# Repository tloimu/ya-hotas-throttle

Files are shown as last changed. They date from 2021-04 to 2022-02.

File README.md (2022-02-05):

# Yet-Another HOTAS Throttle (YA-HOTAS-THROTTLE)

This 3D printable HOTAS throttle game controller. It connects as a standard USB joystick to Windows without needing to install any software.

It has:

 - 3 axis (throttle, vertical, horizontal) with center detents an all
 - 7 buttons
 - hat switch with 8 directions and press button
 - lock/program button
 - RGB LED indicating state: throttle center (green), locked (red), program (blue)
 - high quality mechanical and electro-mechanical components
 - very smooth and easy throttle action with no stiction
 - adjustable throttle handle angle (twist) for better ergonomics at different table positioning
 - customizable throttle axis detents
 - host additional USB serial connectivity for debugging and programming

**Complete Design Explosion View**

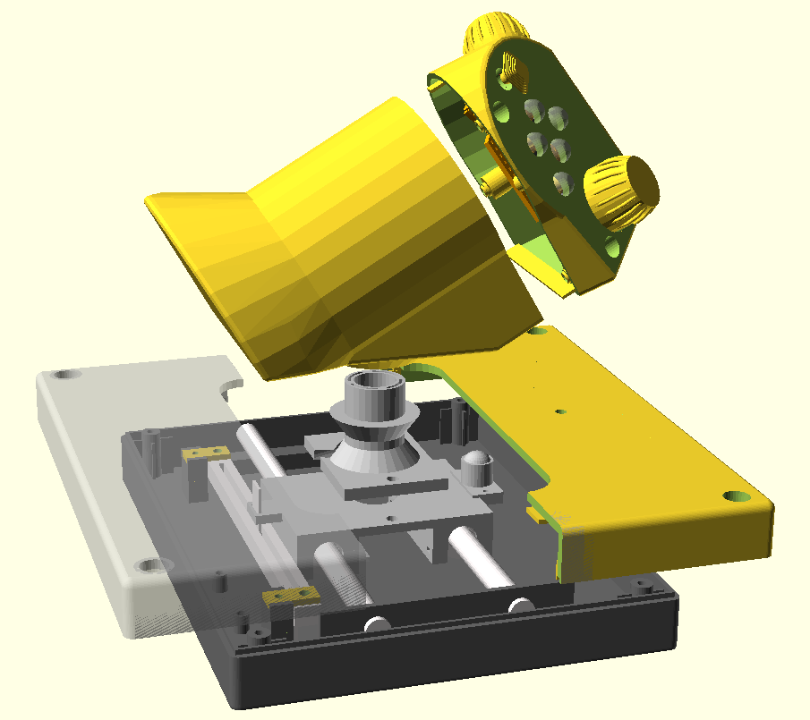
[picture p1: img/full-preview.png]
Full Preview


**A photo of an actual build (don't mind the colors - this is a fully working prototype build)**

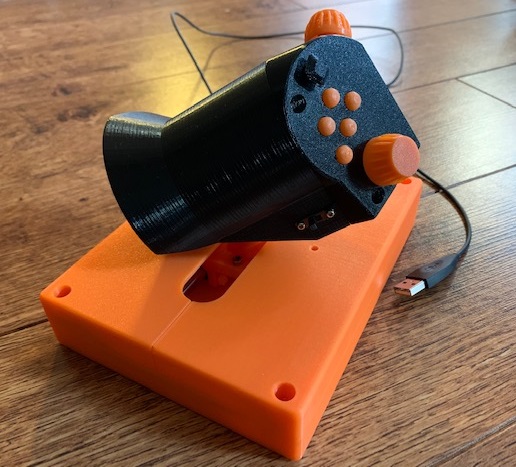
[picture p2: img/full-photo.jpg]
Full Photo


**And when fully opened**

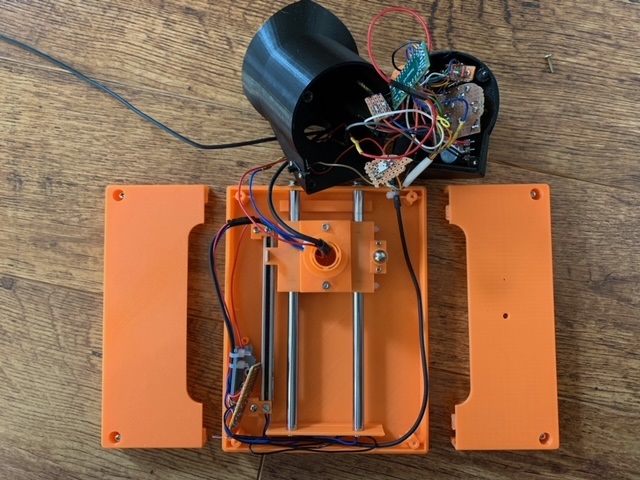
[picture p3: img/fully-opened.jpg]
Fully Opened Photo


# Design

The design is based on these guidelines:

 - all buttons and knobs must be reachable without moving the palm on the hand
 - smooth and precise throttle operation
 - angled design for better ergonomics to miminize stress of the wrist and arm
 - parameterized design for tweaking ergonomics and control placement
 - allow some key build-time mechanical tuning options in case printing precision is not perfect
 - modularity for better flexibility and extensibility

The design is mostly parametrisized so that you can customize it to fit e.g. a bit larger hands better or different angles. This one is optimized for my smaller hands (e.g. Saitek X45 throttle was too big for my hands) so that I can reach all knobs and switches without moving my palm.

The microcontroller was placed in the handle section to minimize the amount of wires needed to be moved as the throttle is used. This and the cable management was design to allow completely smooth operation of the throttle so that the cables won't hinder or move the throttle at any position.

# Build

All 3D printable parts are designed using OpenSCAD and I printed them using my Prusa MK3S running the default .40mm nozzle. Most parts can be printed with 0.30mm layer height but some require 0.20mm layers to get proper results.

Before printing the thumb-side, add supports to the couple of screw locations like below.

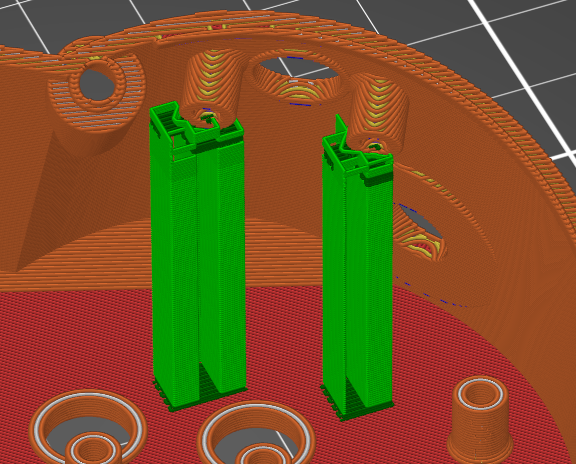
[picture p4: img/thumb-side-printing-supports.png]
Printing supports on the thumb side


Some parts require or benefit from post-print processing:

 - drill the five button holes with e.g. 8.5mm drill to make the button hole walls smooth and the buttons will work smoother - you might also need to gently file the outsides of the buttons too if there is stuff left from printing to get them fit and move well
 - some screw holes may benefit from drilling for easier fit (2.5mm for inner screwholes and 3mm for screwholes on circuitboards)
 - throttle center detent hole could be drilled bigger for stronger detent or cone shaped with a bit larger drill head for smoother detent exit/entry

Below is an illustration of all printable parts.

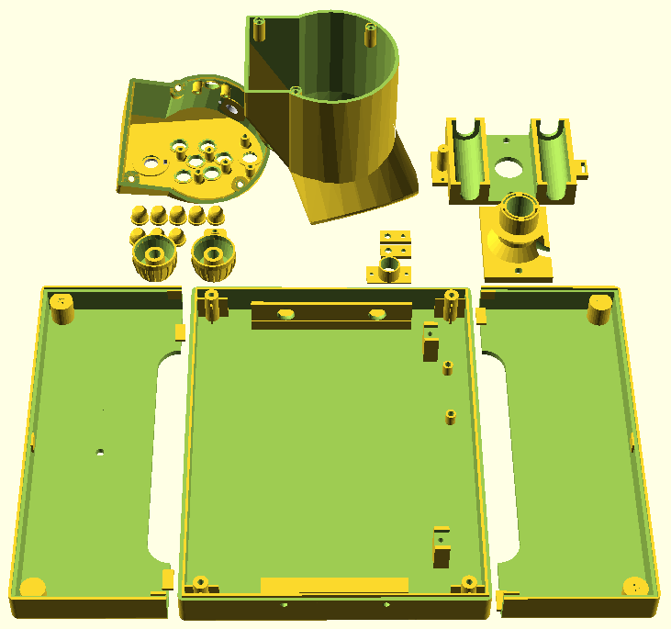
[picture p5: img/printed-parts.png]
Preview of all printed parts


Connect the wires like this to match the code:

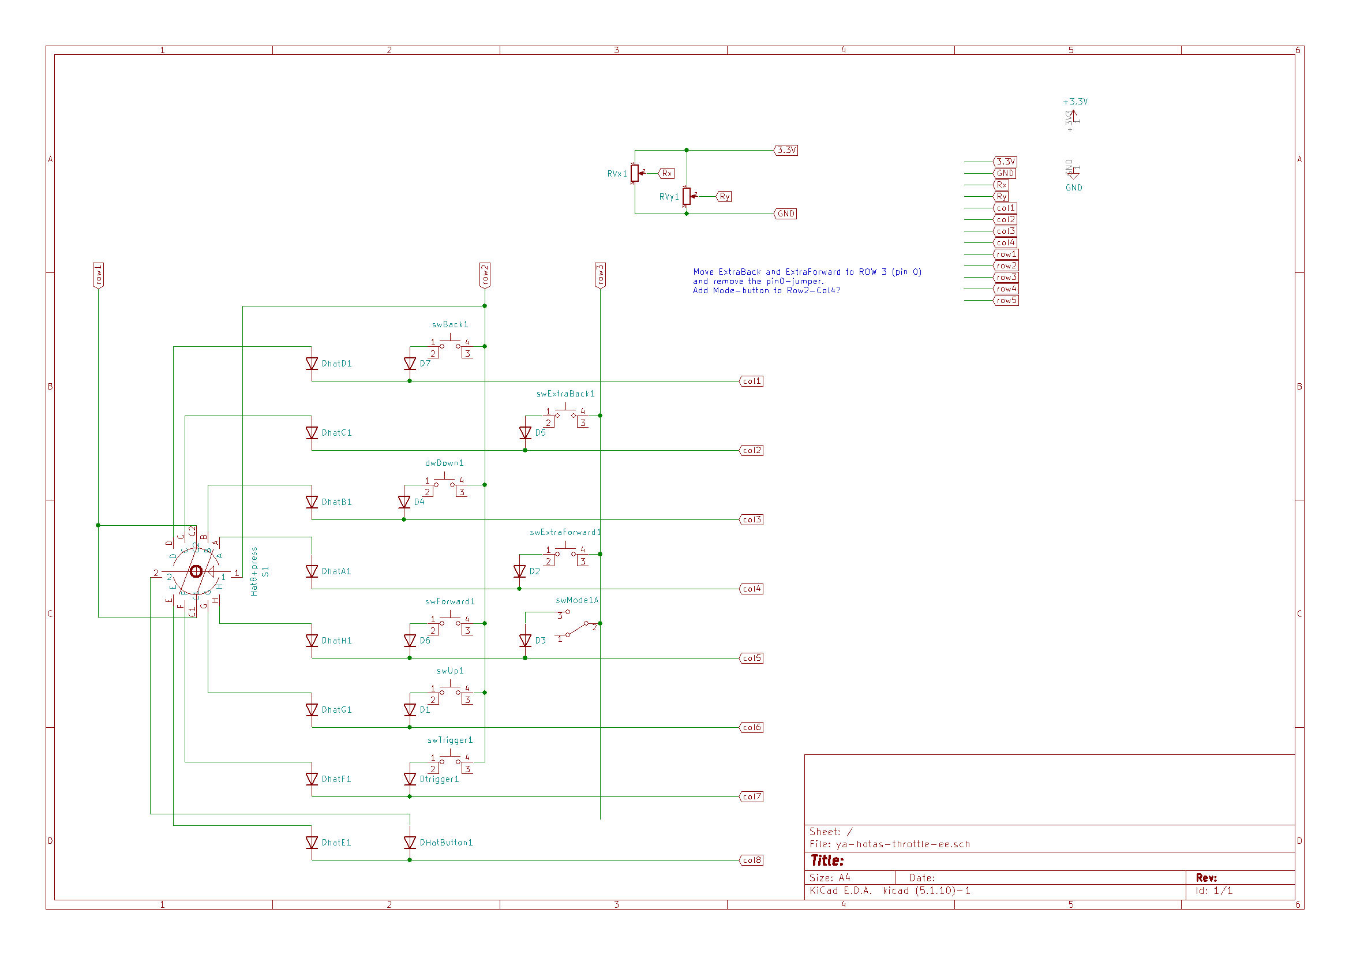
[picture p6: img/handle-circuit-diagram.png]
Circuit Diagram


| Arduino Pin | Circuit  |
| ---- | ---- |
| 8 | Row 1 |
| 6 | Row 2 |
| 0 | Row 3 |
| 10 | Col 1 |
| 4 | Col 2 |
| 9 | Col 3 |
| 1 | Col 4 |
| 12 | Col 5 |
| 5 | Col 6 |
| 7 | Col 7 |
| 11 | Col 8 |
| 21 | Rx |
| 22 | Ry |
| 20 | Throttle |
| 19 | Slider |

The circuit board could look like the below if you use a generic 2.54mm raster board with single sided copper stripes.

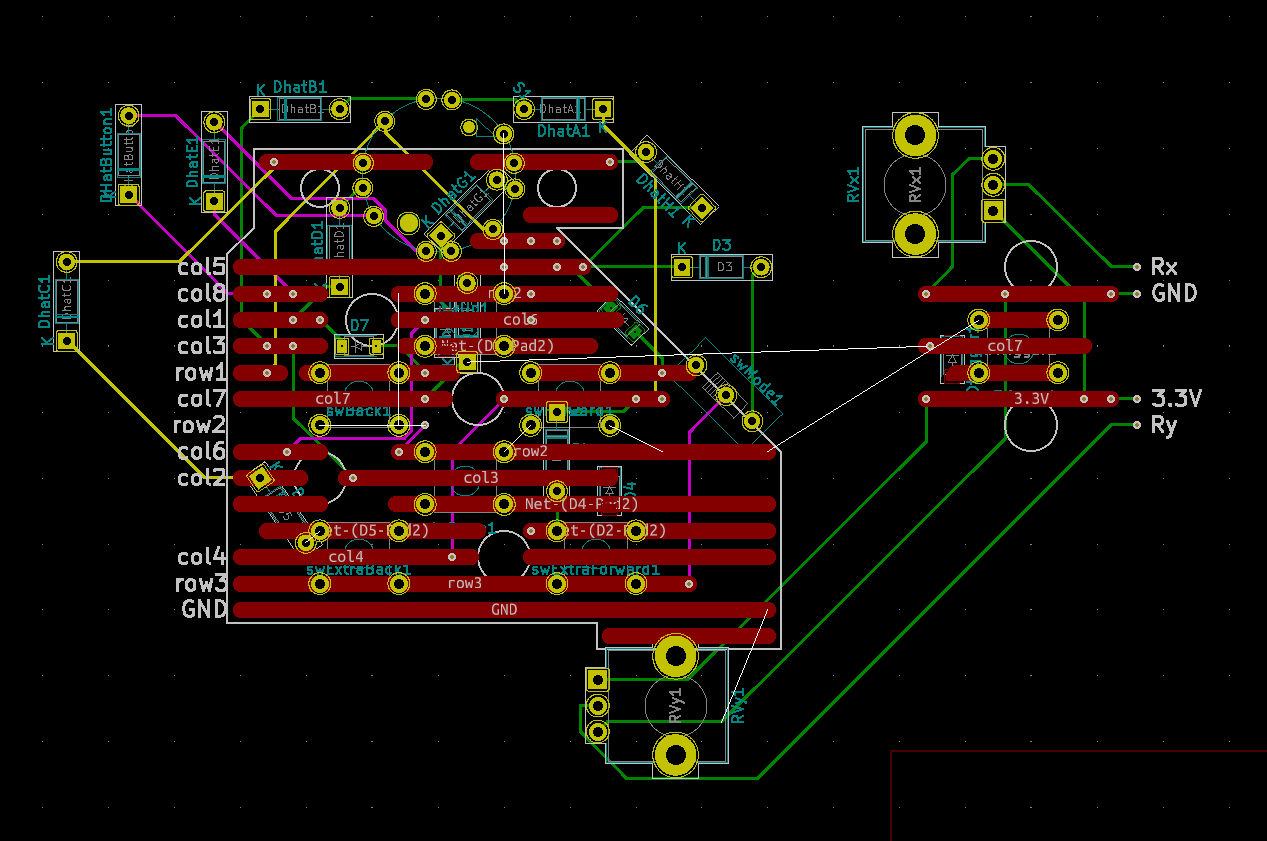
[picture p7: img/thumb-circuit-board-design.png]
Circuit Board Layout


Below are some photos of the assembly

Fully Opened Photo

outside of the handle

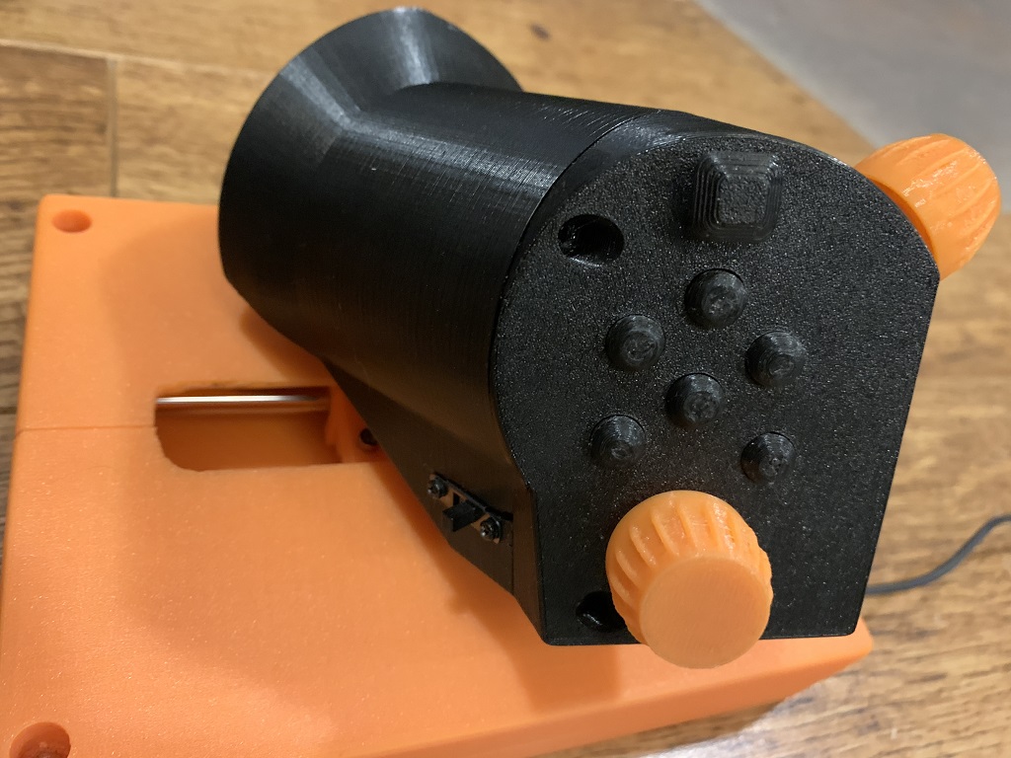
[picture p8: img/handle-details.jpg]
Handle Details


and how to fit everything inside the handle

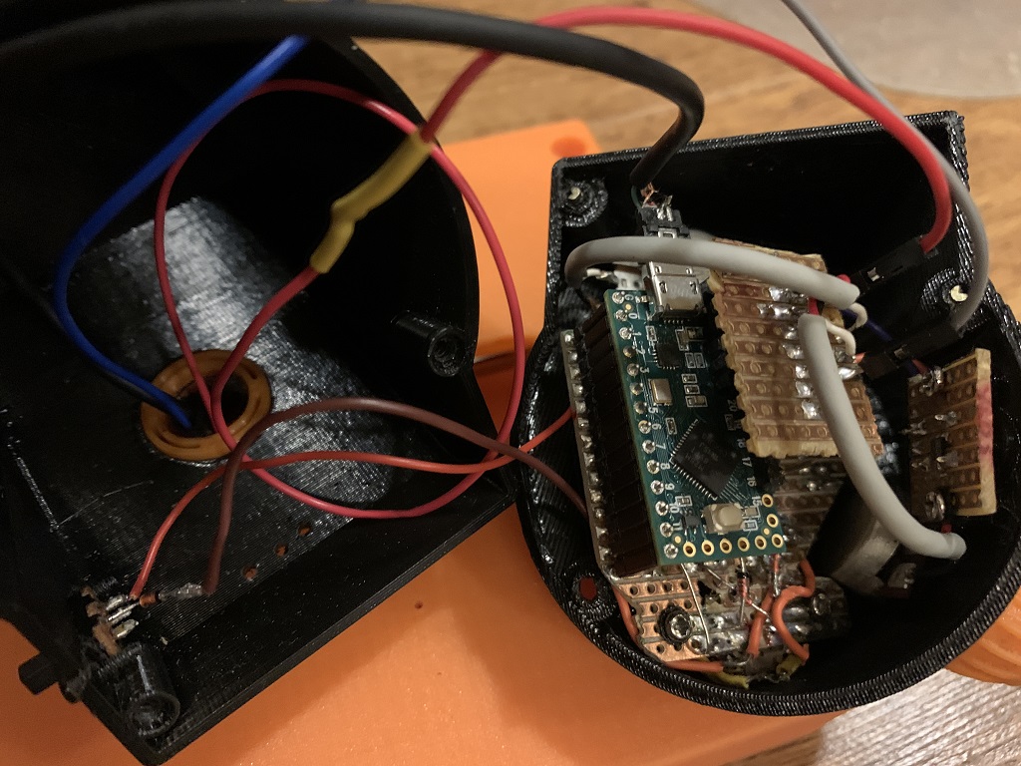
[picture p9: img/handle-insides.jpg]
Fitting Everything In the Handle


The cable management is important to make the throttle handle move smoothly and not move on its own at any position due wires pushing it.

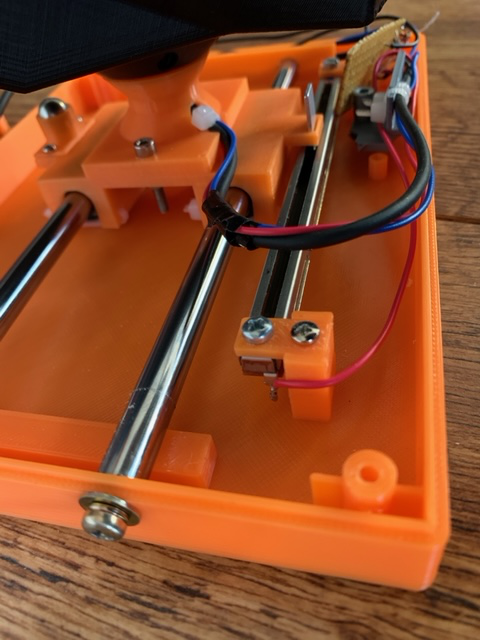
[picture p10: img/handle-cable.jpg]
Handle Cable Management


## Firmware

Directory **firmware** contains the code for Arduino. I has been tested with Arduino 1.8.9 on Teensy LC with USB Type **Serial + Keyboard + Mouse + Joystick**. You also need to have/install **Bounce2** and **FastLED** libraries. Prebuilt hex-file for Teensy LC is also located in the directory.

## Other Build Notes

Lighly lube the two metal rails, just like you would do for your 3D printer rails.

Ligtly lube the ball spring plunger with silicone based (or other plastic friently lube) for smoother throttle movement and less noise.

The right side of the case top that has the center detent - to get smoother and less noisy throttle movement:

 - apply little silicone lube spray to where the ball spring plunger meets the plastic
 - 3D print it so that the last layer is printed in the same direction as the ball moves! E.g. in Prusa slicer, I rotated this part 45 degrees before printing - see the pic below

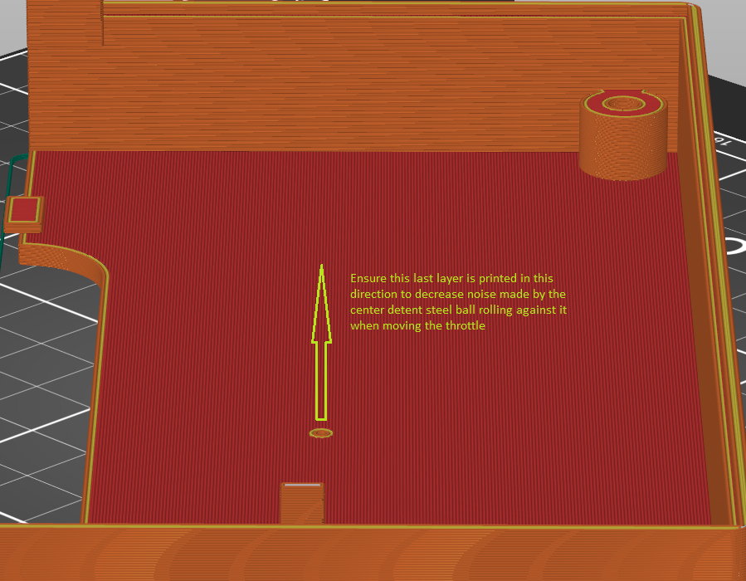
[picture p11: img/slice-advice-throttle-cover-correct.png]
Correct layer print direction for right cover top


The X/Y potentiometers' metal shafts I got required good lubing (e.g. CRC Elektro or teflon spray). They were quite stiff to turn, but lubing them made a big difference. I didn't have this sort of issue with other pots I had, but since I wanted ones with a center detent built-in, had to go with these.

This build does not use a keyboard diode matrix as Teensy LC has enough pins for all the current design's pots and switches. And still has some extra room available. For other Arduino boards with less pins, you would need to make a keyboard diode matrix and change the software to get the button states e.g. via **Keypad** Arduino library.

# Parts List

On top of the 3D printable components, you need

 - 2 x linear motion rods 8mm x 168mm (get one longer and cut in two)
 - 2 x linear bearings 8x15x45 (e.g. LM8LUU)
 - 1 x Teensy LC (or another Arduino board with enough pins)
 - 2 x 10kohm LIN pot (e.g. BI Technologies/TT Electronics P160 with center detent, 15mm shaft - P160KN-1QC15B10K)
 - 1 x 100mm travel 10kohm LIN slide pot (BI Technologies/TT Electronics PS100 B 10K 0E)
 - 1 x multidirectional switch 8 dir + center press (Alps RKJXL100401V)
 - 7 x switches (a tact switch with pins fitting the circuit board listed)
 - 1 x slide switch (any generic model you can fit the case)
 - some generic circuit board (0.1" / 2.54mm pin pitch)
 - N x screws (2.5mm and 3mm) for plastic - for case cover, handle thumb section and internal parts
 - 2 x screws 3mm for attaching the rods from one of their ends to the case
 - 2 x screws 2mm for attaching the slide potentiometer
 - 6 x zip ties for attaching the bearings and do cable management, small ones will do
 - wires
 - 1 x RGB LED (WS2812 compatible)
 - 1 x 9.5mm steel ball
 - 1 x steel spring of e.g. 4.5x22mm (one from a regular ball point pen will work well)

The Teensy LC can quite easily be replaced with any Arduino compatible device with USB connectivity and enough pins. With more coding effort any USB capable micro controller that fits the case could also do.

The RGB LED and slide switch (lock/program) are fully optional. The multi-directional hat switch can also easily be left out or replaced with a simpler 4-directional hat switch.

The steel ball and spring are used to make the center detent for the throttle. Different size ball and spring can be used by modifying the printed *BallSpringPlunger* parameters in the OpenSCAD files.

## Lock/Program

I had two options of the Lock-button. One is a slider switch (currently implemented) and another is to use a simple button switch. Either way, once Lock-mode is on, the throttle axis value is locked to its current value. This is to prevent in-game accidents while you're e.g. AFK and your cat jumps on the throttle.

For simple buttons, the following logic could be made. Press and hold Lock-button for a while and all axis will lock onto their current position. Unlock by pressing Lock button once. Double-click Lock-button to switch between secondary mode that redefines all buttons, hat and axis.

# Discussions and Considerations

## Pots vs Hall effect vs rotation encodes

I did consider using hall sensors or even rotational encoders with belt/pulley system, but eventually found them overly complex to assemble over using simple linear slide potentiometer. We're building these by ourselves and making it all too complex only makes less people (including me) actually build it successfully in quality.

The ones I used here (TT Electronics' PS100) are very smooth, accurate enough and are rated for 100000 cycles while costing only 4-5 euros a piece. So, if they still wear out at some point, just replace it with a new one. It's *your* own build anyway and not something you sell in millions while staying clear of warranty claims.

Many rotary systems might also require manual calibration every time the machine is restarted as the absolute position is not necessarily known. I've seen some hall sensor joysticks requiring that and I found it an undesired feature.

I also considered using some form of lever system (like is done e.g. in Thrustmaster's throttle unit) and transfer the linear motion into a rotational potentiometer. But they easily come with some mechanical "play". Also, some inherent non-linearity of such construct would have to be compensated in the code.

## Throttle Handle Twist or Not

The current design allows either fixing the handle in place with a screw or leave the screw out and allow rotating the handle to a location that suits your current sitting position. The fitting of the throttle shaft to the handle is quite stiff on purpose.

It would be relatively easy to add an actual axis to the twist of the handle. Some throttles have a rocker on the front for this. However, I didn't add that here as rudder pedals or joystick with a twisting handle works better. This throttle is *very* smooth and light to operate so asserting any other forces with the same hand would likely interfere with the throttle.

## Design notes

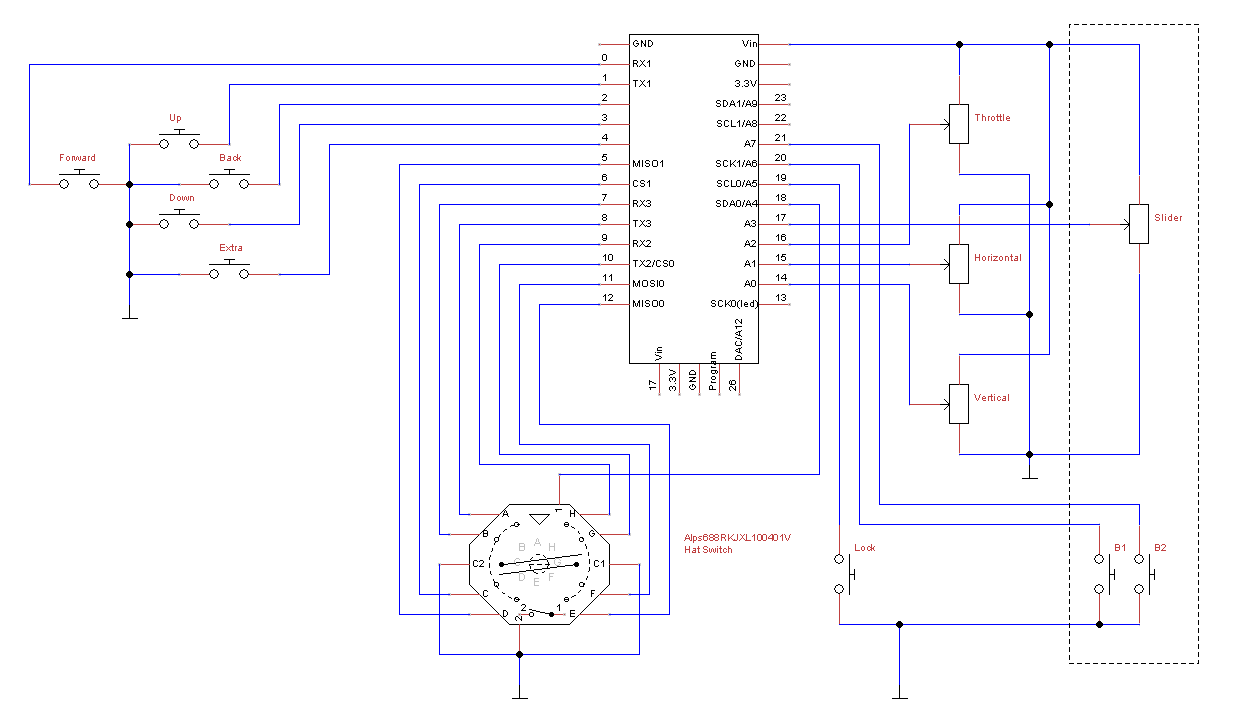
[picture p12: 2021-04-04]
img/throttle-circuit-tinycad.png

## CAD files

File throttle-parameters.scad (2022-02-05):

// Rendering

throttleValue = 1; // Position the throttle when drawing the whole throttle unit
separation = 0; // Separation for making exploded view
drawOtherParts = false; // Whether to render non-printable parts as well in preview mode
showKnobs = false; // Whether to render all knobs as well (heavy calculation warning)
$fn = $preview ? 30 : 100;

draw_other_parts = $preview ? drawOtherParts : false;

// Throttle axis

throttle_travel = 100; // Potentiometer travel length
throttle_offset = 14 + 49/2; // Offset of the base from the center-zero
throttle_lever_distance = 7; // Distance of the potentiometer lever from the side of the base
throttle_lever_width = 8.0; // Width of the potentiometer lever
bearing_height = 15;
bearing_length = 45;

// Throtte handle shape

throttle_handle_length = 60; // The length of the center section of the handle

// Case

case_thickness = 3;
case_bottom_gap = 3; // Gap between inside case bottom and throttle base
case_depth = 17; // outer height of the bottom of the case
case_outside = [2 * throttle_offset + throttle_travel + 5, 140];
case_cover_height = 18; // outer height of the top of the case
grooveClearance = 2;

shaft_length = 31; // Length of the shaft of the handle
shaft_intrusion = 11;

detent_ball_offset = 0;
detent_values = [[0.75, 0.5], [0.5, 4]]; //[[0.7, 1.7], [0.5, 4], [0.25, 1.7]];

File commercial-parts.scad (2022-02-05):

include <common.scad>;

module TeensyPlusPlus()
{
    color ("Green") cube ([51,18,2]);
    
    color ("Snow")
    translate ([0,5,2])
    cube ([9,8,4]);
}

module SlidePotentiometer(range=100, leverWidth=8.0, leverHeight=20,
	sliderEndLength=10, sliderHeight=6.4,
	value=0.5, alignTop=false, alignPin=false, alignLever=false, alignValueMax=false)
{
    slider_length = range + leverWidth + 2 * sliderEndLength;
    slider_width = 8.3;
    lever_thickness = 1.0;
	pin_length = 4.4;
    lever_groove_offset = (slider_length - range - slider_width) / 2;
	lever_offset = sliderEndLength + range * value;

	alignZ = alignTop ? -sliderHeight : (alignPin ? pin_length : 0);
	alignX = alignValueMax ? -sliderEndLength : 0;
	alignY = alignLever ? -slider_width/2 : 0;
	translate([alignX, alignY, alignZ])
	{
		// Slider base
		difference ()
		{
			cube ([slider_length,slider_width,sliderHeight]);
			translate ([lever_groove_offset, (slider_width-lever_thickness*2)/2, 1])
				cube ([range + slider_width,lever_thickness*2,sliderHeight]);
			// Screw places
			translate ([slider_length - 4, slider_width/2, sliderHeight - 3]) cylinder (d=3, h=4);
			translate ([4, slider_width/2, sliderHeight - 3]) cylinder (d=3, h=4);
		}
		// Lever
		translate ([lever_offset, (slider_width-lever_thickness)/2, 0])
		cube ([leverWidth,lever_thickness,leverHeight]);
		// Pins
		color("white") translate ([0, 0, -pin_length])
		{
			translate ([0, slider_width-1, 0]) cube ([0.5,1,pin_length]); // +V
			translate ([slider_length-0.5, 0, 0]) cube ([0.5,1,pin_length]); // GND
			translate ([slider_length-0.5, slider_width-1, 0]) cube ([0.5,1,pin_length]); // R
		}
	}
}

module PotentiometerBourns95A1()
{
	shaft_diameter = 6.3;
	color("blue") cylinder(d1=shaft_diameter, d2=shaft_diameter, h=22.5);
	color("white") cylinder(d1=9.4, d2=9.4, h=9.5);

	base_height = 12.5;
	color ("blue")
	translate ([-17.5/2,-16/2,-base_height])
	cube ([17.5, 16, base_height]);

	// pins
	translate ([-17.5/2-5.5,-7.5/2,-4.5-5.5])
	color("white") cube([5.5, 7.5, 4.5]);
}

module PotentiometerBourns95A1Down()
{
	rotate ([180,0,0])
	PotentiometerBourns95A1();
}

// Bourns PCW1J-B24-CCB103L
module PotentiometerBournsPCW1J()
{
	shaft_diameter = 6.3;
	color("black") cylinder(d1=shaft_diameter, d2=shaft_diameter, h=19);
	color("white") cylinder(d1=8.8, d2=8.8, h=6.5);

	base_height = 7.2;
	color ("black")
	translate ([-22.5/2,-22.5/2,-base_height])
	cube ([22.5, 22.5, base_height]);

	// notches
	translate ([0,22.5/2-1.3,1])
	color("grey") cube([2.7, 1.3, 2], center=true);

	// pins
	translate ([-22.5/2-7,-12/2,2-base_height])
	color("white") cube([7, 12, 0.7]);
}

module PotentiometerBournsPCW1JDown()
{
	rotate ([180,0,0])
	PotentiometerBournsPCW1J();
}

// BI/TT P160 pot with 15mm shaft (e.g. LIN 10kohm pot P160KN-1QC15B10K)
module PotentiometerBIP160(flip = false, cavityOnly = false)
{
    base_diameter = 16.5;
    base_height = 9.4;
    shaft_neck_height = 6.4;
    shaft_neck_diameter = 6.9;
    shaft_diameter = 6.0;
    shaft_length = 24.4 - base_height - shaft_neck_height;
    notch_width = 1.2;
    notch_length = 2.7;
    notch_height = 11.4 - base_height;
    pin_distance = 5.0;
    pin_level = 0.0;
    pin_length = 8.0;

    rotate([0,flip ? 180 : 0,0])
    {
        if (cavityOnly == false)
        {
            translate([0,0,shaft_neck_height])
            color("silver") cylinder(d=shaft_diameter, h=shaft_length);
            color("silver") cylinder(d=shaft_neck_diameter, h=shaft_neck_height);

            color ("silver")
            translate ([0,0,-base_height])
            cylinder (d=base_diameter, h=base_height);

            // pins
            translate ([0,-pin_distance,pin_level - 2.0])
            color("silver") cube([base_diameter/2 + pin_length, 2*pin_distance, 2.0]);

            // Notch
            rotate([0,0,-90])
            translate ([base_diameter / 2 - notch_width, -notch_length/2, 0])
            color("silver") cube([notch_width, notch_length, notch_height]);
        }
        else
        {
            tolerance = 0.4;
            // Shaft hole
            color("silver") cylinder(d=shaft_neck_diameter + tolerance, h=shaft_length + shaft_neck_height);
            // Notch cavity
            rotate([0,0,-90])
            translate ([base_diameter / 2 - notch_width - tolerance/2, -notch_length/2 - tolerance/2, 0])
            color("silver") cube([notch_width + tolerance, notch_length + tolerance, notch_height + tolerance]);
        }
    }
}

// 8-direction + push button switch
module AlpsRKJXL100401V()
{
	color("brown")
	{
		// Case
		rotate([0,0,45])
		difference()
		{
			rotate([0,0,22.5])
			cylinder(d=14.4, h=6.4, $fn=8);

			// Cover markings
			translate([0,4,0]) cube([0.5,2,1], center = true);
			translate([0,-4,0]) cube([0.5,2,1], center = true);
			translate([4,0,0]) cube([2,0.5,1], center = true);
			translate([-4,0,0]) cube([2,0.5,1], center = true);

			rotate([0,0,-45])
			translate([7,0,-0.5]) rotate([0,0,60]) cylinder(d=4, h=1, $fn=3);
		}

		// Shaft
		difference()
		{
			translate([0,0,-7])
			cylinder(d=2.2, h=7);

			translate([0.3,-1.1,-7.01])
			cube([0.81, 2.20, 3.51]);
		}

		// Installation guides at the bottom
		rotate([0,0,-12.5])
		{
			translate([-6.4+0.8,0,6]) cylinder(d=1.6, h=2.5);
			translate([6.1-0.5,0,6]) cylinder(d=1, h=2);
		}
	}
	// Pins
	translate([0,0,6.4])
	color("white")
	{
		translate([0,7.5,0]) PinFlat(text="C1"); // C1
		translate([0,-7.5,0]) PinFlat(text="C2", d=180); // C2

		translate([7.5,2,0]) PinFlat(text="1", d=-90); // 1
		translate([-7.5,-2,0]) PinFlat(text="2", d=90); // 2

		rotate([0,0,45])
		{
			translate([7.5,1.2,0]) PinFlat(text="G", d=-90); // A
			translate([7.5,-1.2,0]) PinFlat(text="H", d=-90); // B
			translate([-7.5,1.2,0]) PinFlat(text="D", d=90); // A
			translate([-7.5,-1.2,0]) PinFlat(text="C", d=90); // B

			translate([1.2,7.5,0]) PinFlat(text="F", d=0); // A
			translate([-1.2,7.5,0]) PinFlat(text="E", d=0); // B
			translate([1.2,-7.5,0]) PinFlat(text="A", d=180); // A
			translate([-1.2,-7.5,0]) PinFlat(text="B", d=180); // B
		}
	}

	// Instruction texts
	module t(text, d=0)
	{		
		rotate([0,0,d]) translate([0,-5,0]) rotate([180,0,0]) text(text,size=1,halign="center");
	}

	rotate([0,0,90])
	{
		translate([0,7.5,0]) t("1-2",0);
		t("A",0);
		t("E",180);
		t("H",45);
		t("G",90);
		t("F",135);
		t("D",-135);
		t("C",-90);
		t("B",-45);
	}
}

module Gt2Pulley(d=12.5,dShaft=5, l=14, w=6)
{
	color("silver")
	difference()
	{
		cylinder(d=d,h=l);

		translate([0,0,-0.01])
		cylinder(d=dShaft,h=l+0.02);

		translate([0,0,1])
		difference()
		{
			cylinder(d=d+0.01,h=w);
			cylinder(d=d-2,h=w);
		}
	}
}

module DcMotor()
{
	color("silver")
	cylinder(d=15,h=30);
}

module Gt2BeltCircular(l,d=12.5,width=6)
{
	color("brown")
	{
		cube([l, d, 2]);
		translate([0,0,0]) cylinder(d=d,h=width);
		translate([l,0,0]) cylinder(d=d,h=width);
		for (a = [360/16 : 360/16 : 360])
		{
			rotate([0, a, 0]) translate([d/2-2,0,0]) cylinder(d=2,h=width);
		}
	}
}


module SlideSwitch(l=12, w=5, h=5, screwDistance = 16)
{
	translate([-l/2,-w/2,-h])
	cube([l,w,h]);

	difference()
	{
		translate([-screwDistance/2-2,-w/2,-0.5])
		cube([screwDistance+4,w,0.5]);

		translate([-screwDistance/2,0,-1])
		cylinder(d=2, h=2);
		translate([screwDistance/2,0,-1])
		cylinder(d=2, h=2);
	}

	lever = [2, 2, 4];
	translate([-lever.x/2, -lever.y/2, 0])
	cube(lever);
}

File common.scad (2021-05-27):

// Common utilities for building stuff

module flipX() { rotate([180,0,0]) children(); }
module flipY() { rotate([0,180,0]) children(); }
module flipZ() { rotate([0,0,180]) children(); }
module turnX(a) { rotate([a,0,0]) children(); }
module turnY(a) { rotate([0,a,0]) children(); }
module turnZ(a) { rotate([0,0,a]) children(); }
module moveX(l) { translate([l,0,0]) children(); }
module moveY(l) { translate([0,l,0]) children(); }
module moveZ(l) { translate([0,0,l]) children(); }

module sheet_cone(x, y1, y2, h)
{
	points = [[0,0,0],  [0,y1,0],  [0,y1/2+y2/2,h],  [0,y1/2-y2/2,h],
			  [x,0,0], [x,y1,0], [x,y1/2+y2/2,h], [x,y1/2-y2/2,h]];
	faces = [[0,1,2,3],  // bottom
			[4,5,1,0],  // front
			[7,6,5,4],  // top
			[5,6,2,1],  // right
			[6,7,3,2],  // back
			[7,4,0,3]];
	polyhedron(points=points, faces=faces, convexity=10);
}

module tube(radius, length, thickness)
{
    difference ()
    {
        cylinder (r=radius,h=length);
        translate ([0,0,-1])
        cylinder (r=radius-thickness,h=length + 2);
    }
}

module tubeD(dout, din, h)
{
    difference ()
    {
        cylinder (d=dout,h=h);
        translate ([0,0,-1])
        cylinder (d=din,h=h + 2);
    }
}

module tubeD2(dout1, din1, dout2, din2, h)
{
    difference ()
    {
        cylinder (d1=dout1, d2=dout2, h=h);
        translate ([0,0,-1])
        cylinder (d1=din1, d2=din2, h=h + 2);
    }
}


module washer(out, in, h)
{
    difference ()
    {
        cylinder (d=out,h=h);
        translate ([0,0,-1])
        cylinder (d=in-h,h=h + 2);
    }
}

module hole(diameter, length)
{
    translate ([0,0,-1])
    cylinder (r1=diameter/2, r2=diameter/2, h=length + 2);
}

module cube_inside(size, thickness)
{
	translate ([thickness, thickness, thickness])
	cube ([size[0] - thickness*2, size[1] - thickness*2, size[2] - thickness*2]);
}

module DetentPotSpring(dShaft= 9.5, dBolt = 14.5, length = 6, contactLength = 2)
{
	dOut = dBolt + 2.2;
	hull()
	{
		translate([0,dBolt/2+0.4,-contactLength])
		{
			translate([0,0.58,0])
			cylinder(d=1.2, h=contactLength);
		}
		translate([0,dBolt/2+0.6,-contactLength - 1])
		cylinder(d=1.2, h = contactLength + 1);
	}
	// Spring shaft
	difference()
	{
		translate([0,dBolt/2+0.6,-length - contactLength - 0.5])
		cylinder(d=1.2, h = length + contactLength - 0.5);

		translate([0,0,-length - contactLength + 0.2])
		cylinder(d=dBolt, h=4); // bolt
	}

	washerThickness = 0.7;

	// Mounting washer with surface ripples for better grip
	translate([0,0,-length - contactLength - 0.5])
	difference()
	{
		tubeD(dOut, dShaft, washerThickness);

		for (a = [100:15:440])
		{
			translate([0,0,-1.2])
			rotate([45,0,a+7])
			cube([dBolt/2+2,1,1]);
			translate([0,0,0.5])
			rotate([45,0,a])
			cube([dBolt/2+2,1,1]);
		}
	}
}

// Kobs and knob holes (D/T)
module Knob(d1, d2, length, skirt=5, detent = false)
{
	aargh = true;
	difference()
	{
		union()
	{
	// Pot shaft holder
	translate([0,0,0])
	cylinder (d1=d2, d2=d2, h=length);

	// Outer shell
	difference ()
	{
		cylinder (d1=d1, d2=d2, h=length);
		translate([0,0,-1])
		cylinder (d1=d1-1.5, d2=d2-1.5, h=length-2);
	}

	// Skirt and detent
	translate([0,0,-skirt])
	{
		tube (d1/2, skirt, 1);

		if (detent == true)
		{
			translate([-1,d1/2-1,0])
			cylinder(d=1.5, h=skirt);
			translate([1,d1/2-1,0])
			cylinder(d=1.5, h=skirt);
		}
	}

	for (a = [40:40:360])
	{
		if (aargh == true)
		{
			rotate([0,0,a])
			rotate([90,2,0])
			translate([-5.7,-2.4,0])
			rotate_extrude(angle=60,convexity = 10)
			translate([15.7, 0, 0])
			circle(r = 0.55);
		}
		else
		{
			rotate([0,0,a])
			rotate([90,-9,0])
			translate([-16.9+6.2,-1.2,0])
			rotate_extrude(angle=33,convexity = 10)
			translate([20, 0, 0])
			circle(r = 0.5);
		}
	}
	
	for (a = [20:40:360])
	{
		if (aargh == true)
		{
			rotate([0,0,a])
			rotate([90,-2,0])
			translate([-13.8,-3,0])
			rotate_extrude(angle=41,convexity = 10)
			translate([23.5, 0, 0])
			circle(r = 0.55);
		}
		else
		{
			rotate([0,0,a])
			rotate([90,-9.1,0])
			translate([-16.75,-1.27,0])
			rotate_extrude(angle=30.5,convexity = 10)
			translate([26, 0, 0])
			circle(r = 0.5);
		}
	}
	}
	translate([-15,-15,-20-skirt])
	cube([30,30,20]);
	}
}

module KnobHoleD(diameter = 6, length = 12)
{
	actualD = diameter + 0.2;
	difference ()
	{
		cylinder (d1=actualD, d2=actualD, h=length);
		translate ([actualD / 2 - 1.4,-5,-1])
		cube ([10,10,length + 2]);
		
		// Tightening dips
		for (a = [-1.8:3.6:1.8])
		{
			rotate([0,0,180])
			translate([-7.6,a,5])
			rotate([90,45,0])
			rotate_extrude(angle=90,convexity = 10)
			translate([diameter-0.1, 0, 0])
			circle(r = 0.4);
		}
	}
}

module KnobHoleT(diameter = 6.3, lengthNoSkirt = 12, skirt = 1)
{
	actualD = diameter + 0.2;
	length = lengthNoSkirt + skirt;
	difference ()
	{
		cylinder (d1=actualD, d2=actualD, h=length);
		translate ([-0.6,-actualD,length - 1.8])
		cube ([1.2,2*actualD,2.5]);
		
		// Tightening dips
		translate ([0,0,skirt])
		for (a = [45:90:360])
		{
			rotate([0,0,90 + a])
			translate([-9.4,0,4])
			rotate([90,45,0])
			rotate_extrude(angle=90,convexity = 10)
			translate([diameter-0.1, 0, 0])
			circle(r = 0.4);
		}
	}
}

module KnobT(d1, d2, length, skirt=1, detent=false)
{
	difference ()
	{
		Knob(d1, d2, length, skirt, detent);
		translate ([0,0,-0.2-skirt])
		KnobHoleT(6.4, 12.2, skirt);
	}
}

module KnobD(d1, d2, length)
{
	difference ()
	{
		Knob(d1, d2, length);
		translate ([0,0,-0.2])
		KnobHoleD(6, length=12.2);
	}
}

module ScrewCavity3m(thruDepth, capDepth = 20, capDiameter = 7, thruDiameter = 3.2, thickness=2)
{
	translate([0,0,thruDepth])
	cylinder (d1=capDiameter, d2=capDiameter, h=capDepth);
	translate([0,0,-thickness])
	cylinder (d1=thruDiameter, d2=thruDiameter, h=thruDepth+thickness*2);
}

module ScrewThreadSupport3m(length, angle = [0,0,0])
{
	difference()
	{
		translate([0,0,-length])
		tube (3, length, 1.8);

		rotate(angle)
		translate([-5, -5, 0])
		cube ([10,10,10]);
	}
}

module ScrewEntrySupport3m(thruDepth, capDepth = 20, capDiameter = 7, thickness=2, thruDiameter = 3.2)
{
	translate([0,0,thruDepth-thickness])
	cylinder (d1=capDiameter+thickness, d2=capDiameter+thickness, h=capDepth-thickness);

	translate([0,0,-10])
	cylinder (d1=thruDiameter+thickness, d2=thruDiameter+thickness, h=capDepth-thickness);
}

module Switch()
{
	color("black")
	translate ([-3,-3,-4])
	cube([6,6,3]);

	color("yellow")
	translate ([0,0,-1])
	cylinder(d=3.2,h=1);

	r = 2.54;
	w = 0.8;
	wire_height = 4;
	d = 3 * r / 2;
	color("white")
	translate([-w/2,-w/2,-4-wire_height])
	{
		translate ([-d,-r,wire_height+1]) cube([2*w,w,1]);
		translate ([-d,-r,0]) cube([w,w,wire_height + 1]);

		translate ([d-w,-r,wire_height+1]) cube([2*w,w,1]);
		translate ([d,-r,0]) cube([w,w,wire_height + 1]);

		translate ([-d,r,wire_height+1]) cube([2*w,w,1]);
		translate ([-d,r,0]) cube([w,w,wire_height + 1]);

		translate ([d-w,r,wire_height+1]) cube([2*w,w,1]);
		translate ([d,r,0]) cube([w,w,wire_height + 1]);
	}
}

module SwitchButton(d=8, h=7, cavityOnly=false)
{
	if (cavityOnly == false)
	{
		difference()
		{
			union ()
			{
				intersection()
				{
					translate([0,0,-0.8])
					cylinder(d=d, h=h+0.8);
					translate([0,0,1.6])
					sphere(r=h-0.7);
				}
				translate([0,0,-1])
				cylinder(d=d+1.6, h=0.8);
			}
			translate([0,0,-2])
			cylinder(d=d-1, h=h);
		}

		translate([0,0,-1.4])
		tube(radius=2, length=h, thickness=1);
	}
	else
	{
		translate([0,0,-0.5]) cylinder(d=d, h=10); // button hole
		moveZ(-1.9-0.1) cylinder(d=d+2.2, h=1.9); // make sure buttons don't hit anything
	}
}

SwitchButtonBallOffsetZ = 1.2;
module SwitchButtonBall(d=8, h=7, topRounding=4, text="")
{
	difference()
	{
		union()
		{
			difference()
			{
				union ()
				{
					intersection()
					{
						translate([0,0,-1.2])
						cylinder(d=d, h=h+0.8);
						union()
						{
							translate([0,0,h - topRounding])
							sphere(d=d);
							translate([0,0,(10-topRounding)-d])
							cylinder(d=d, h=h-2);
						}
					}
					translate([0,0,-1.2])
					cylinder(d=d+1.6, h=1.2);
				}
				translate([0,0,-d/2])
				cylinder(d=d-1, h=h);
				translate([0,0,-1.25])
				cylinder(d1=d+0.8, d2=d-1, h=1);

				// Top inner cavity
				translate([0,0,h - 4])
				sphere(d=d-1);
			}

			// Center shaft
			translate([0,0,-1.2])
			cylinder(d=2.5,h=h+0.7);
		}

		if (text != "")
		{
			translate([0,-1.4,h-0.599])
			linear_extrude(height = 0.2)
			text(text,size=3,halign="center");
		}
	}
}

// Hat Switch with 4 directions and center push with 2x2x2mm shaft
// and a case and a knob for it.

module Hat5Switch()
{
	{
		// Slot for the hat switch
		color("grey")
		intersection()
		{
			translate([-4.3,-4.3,0])
			cube ([8.6, 8.6, 3]);

			rotate([0,0,45])
			translate([-4,-4,0])
			cube ([8, 8, 1.8]);
		}
		color("grey")
		translate([0,0,1.8]) cylinder (d1=4.3, d2=3.3, h=0.2);

		color("black")
		{
			// Shaft and base
			translate([-1,-1,2])
			cube ([2, 2, 3]);
			translate([0,0,1.8]) cylinder (d1=3, d2=3, h=0.3);
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

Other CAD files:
knobs.scad
printed-parts.scad
special-parts.scad
throttle-assembly.scad
throttle-base.scad
throttle-case.scad
throttle-handle.scad
throttle.scad

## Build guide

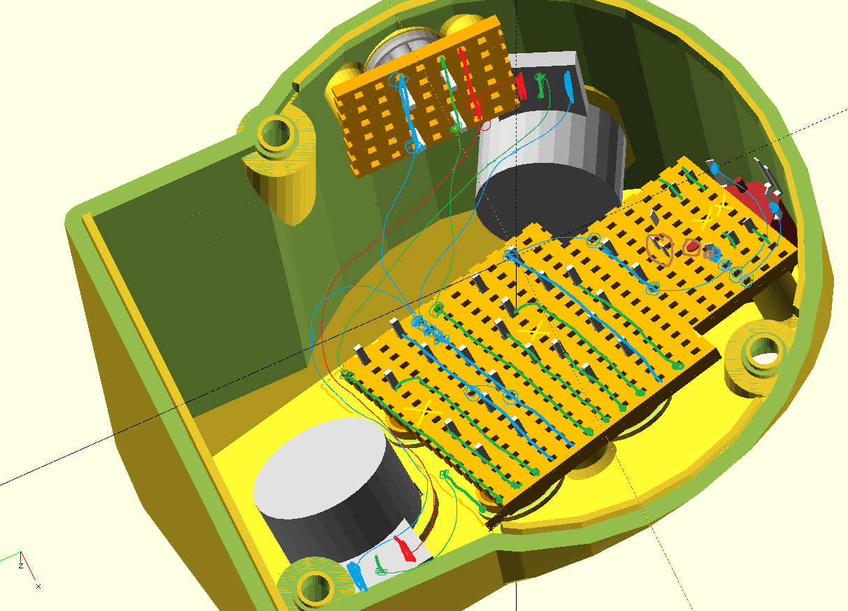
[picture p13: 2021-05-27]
img/wiring-thumb-size.png

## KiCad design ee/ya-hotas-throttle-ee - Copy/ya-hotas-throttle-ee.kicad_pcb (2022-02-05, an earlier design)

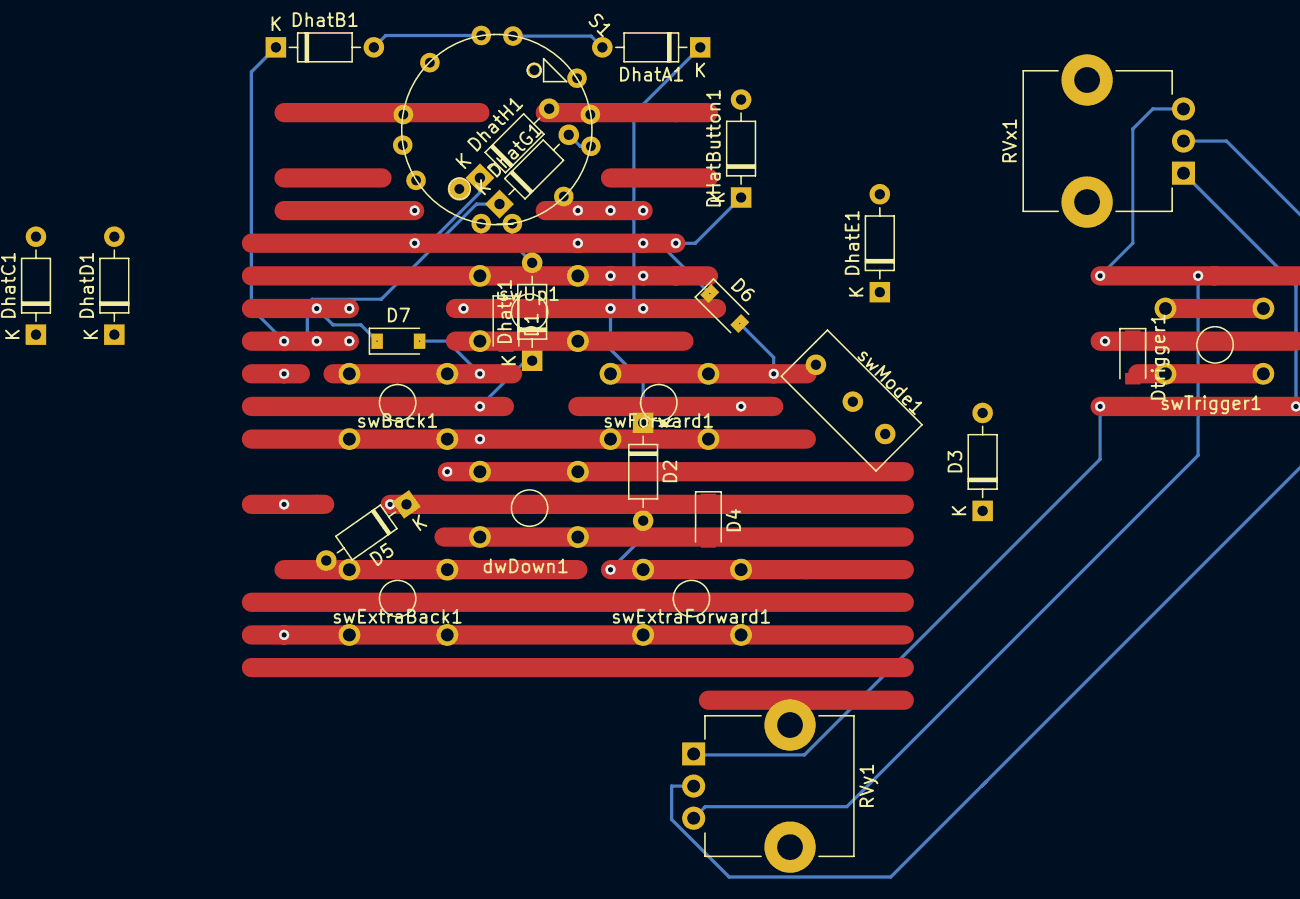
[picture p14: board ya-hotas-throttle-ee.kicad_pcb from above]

Board: 4 copper layers, 28 parts (0 on the bottom side), 27 nets.

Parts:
D1, D4, D6, D7: 1N4148W; D_SOD-123
D2, D3, D5: 1N4148W; D_DO-35_SOD27_P7.62mm_Horizontal
DHatButton1: 1N4148W; D_DO-35_SOD27_P7.62mm_Horizontal
DhatA1: 1N4148W; D_DO-35_SOD27_P7.62mm_Horizontal
DhatB1: 1N4148W; D_DO-35_SOD27_P7.62mm_Horizontal
DhatC1: 1N4148W; D_DO-35_SOD27_P7.62mm_Horizontal
DhatD1: 1N4148W; D_DO-35_SOD27_P7.62mm_Horizontal
DhatE1: 1N4148W; D_DO-35_SOD27_P7.62mm_Horizontal
DhatF1: 1N4148W; D_DO-35_SOD27_P7.62mm_Horizontal
DhatG1: 1N4148W; D_DO-35_SOD27_P7.62mm_Horizontal
DhatH1: 1N4148W; D_DO-35_SOD27_P7.62mm_Horizontal
Dtrigger1: 1N4148W; D_SOD-123
RVx1: R_POT_Small; Potentiometer_TT_P0915N
RVy1: R_POT_Small; Potentiometer_TT_P0915N
S1: Hat8+press; AlpsRKJXL100401V
dwDown1: SW_MEC_5E; Switch_Tact
swBack1: SW_MEC_5E; Switch_Tact
swExtraBack1: SW_MEC_5E; Switch_Tact
swExtraForward1: SW_MEC_5E; Switch_Tact
swForward1: SW_MEC_5E; Switch_Tact
swMode1: SW_DPDT_x2; Switch_slide_2
swTrigger1: SW_MEC_5E; Switch_Tact
swUp1: SW_MEC_5E; Switch_Tact

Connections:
3.3V: RVx1.1, RVy1.1
GND: RVx1.3, RVy1.3
unnamed: D1.2, swUp1.1
unnamed: D2.2, swExtraForward1.1
unnamed: D3.2, swMode1.3
unnamed: D4.2, dwDown1.1
unnamed: D5.2, swExtraBack1.1
unnamed: D6.2, swForward1.1
unnamed: D7.2, swBack1.1
unnamed: DHatButton1.2, S1.1
unnamed: DhatA1.2, S1.A
unnamed: DhatB1.2, S1.B
unnamed: DhatC1.2, S1.C
unnamed: DhatD1.2, S1.D
unnamed: DhatE1.2, S1.E
unnamed: DhatF1.2, S1.F
unnamed: DhatG1.2, S1.G
unnamed: DhatH1.2, S1.H
unnamed: Dtrigger1.2, swTrigger1.1
col1: D1.1, D2.1, D7.1, DhatA1.1
col2: D4.1, D5.1, DhatC1.1, DhatE1.1
col3: DhatD1.1, DhatF1.1
col4: DhatB1.1, DhatG1.1, Dtrigger1.1
col5: D6.1, DHatButton1.1, DhatH1.1
row1: S1.C1, swUp1.4
row2: S1.2, swExtraBack1.4, swExtraForward1.4
row4: dwDown1.4, swBack1.4, swForward1.4, swTrigger1.4

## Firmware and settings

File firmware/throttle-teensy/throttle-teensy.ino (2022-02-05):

/* Throttle unit USB adapter for Teensy LC

  The Throttle unit has keyboard diode matrix for buttons, hats and mode switches.
*/
//#define BOUNCE_WITH_PROMPT_DETECTION
#include <FastLED.h>
//#include <Bounce2.h>
#include <Keypad.h>

boolean gDebugToSerial = false;

class Axis
{
public:
  int rawValue;
  int value;
  int deadZone;
  int maxValue;
  int minValue;
  int centerValue;
  char name;

  Axis(char name = 'A')
  {
    this->name = name;
    this->value = 0;
    this->rawValue = 0;
    this->deadZone = 4;
    this->maxValue = 1020;
    this->minValue = 3;
    this->centerValue = 511;
  }

  void calcValue(int rawValue)
  {
    if (rawValue != this->rawValue)
    {
      this->rawValue = rawValue;
      int value = this->valueToPosition(rawValue);
      if (gDebugToSerial && value != this->value)
      {
        Serial.print("Axis ");
        Serial.print(this->name);
        Serial.print(": ");
        Serial.print(value);
        Serial.print(" (");
        Serial.print(rawValue);
        Serial.println(")");
      }
      this->value = value;
    }
  }

  int valueToPosition(int rawValue)
  {
   // Min/max
   if (rawValue >= this->maxValue)
    return 1023;
   if (rawValue <= this->minValue)
    return 0;
    
   int pos = rawValue - this->centerValue;
   
   // Dead-zone
   if (pos > -this->deadZone && pos < this->deadZone)
    return 511;

  // Curves
  if (pos > 0)
   {
    // Top-side curve
    pos = rawValue - this->centerValue - this->deadZone;
    unsigned long l = this->maxValue - this->centerValue - this->deadZone;
    return (((unsigned long) pos) * (unsigned long) 512) / l + 511;
   }
   else
   {
    // Bottom-side curve
    pos = rawValue - this->minValue;
    unsigned long l = this->centerValue - this->minValue - this->deadZone;
    return (((unsigned long) pos) * (unsigned long) 512) / l + 0;
   }
  }
};

// Modes
const byte MODE_STARTUP = 0;
const byte MODE_NORMAL = 1;
const byte MODE_LOCKED = 2;
const byte MODE_ALT = 4;

byte mode = MODE_NORMAL;
byte throttleCentered = 0;
Axis axisThrottle('T');
Axis axisHor('X');
Axis axisVer('Y');

byte previousMode = MODE_STARTUP;
byte previousThrottleCentered = 0;

// Led drives

#define NUM_LEDS    1
CRGB leds[NUM_LEDS];
const byte pinLed = 13;

// Mapping pins to buttons and axis

const int ROW_NUM = 3;
const int COLUMN_NUM = 8;

byte pin_rows[ROW_NUM] = { 8, 6, 0 };
byte pin_column[COLUMN_NUM] = { 10, 4, 9, 1, 12, 5, 7, 11 };

const byte pinHatButton = 'H';
const byte pinHatA = 'a';
const byte pinHatB = 'b';
const byte pinHatC = 'c';
const byte pinHatD = 'd';
const byte pinHatE = 'e';
const byte pinHatF = 'f';
const byte pinHatG = 'g';
const byte pinHatH = 'h';

const byte pinUp = 'U';
const byte pinDown = 'D';
const byte pinForward = 'F';
const byte pinBack = 'B';
const byte pinExtraForward = '>';
const byte pinExtraBack= '<';
const byte pinTrigger = 'T';
const byte pinModeSwitch = 'M';

const byte pinNC = '-';

const byte analogPinThrottle = 20;
const byte analogPinHor = 21;
const byte analogPinVer = 22;
const byte analogPinSlider = 19;

char keys[ROW_NUM][COLUMN_NUM] = {
  {pinHatD, pinHatC, pinHatB, pinHatA, pinHatH, pinHatG, pinHatF, pinHatE},
  {pinBack, pinNC, pinDown, pinNC, pinForward, pinUp, pinTrigger, pinHatButton},
  {pinNC, pinExtraBack, pinNC, pinExtraForward, pinModeSwitch, pinNC, pinNC, pinNC},
};

Keypad keypad = Keypad( makeKeymap(keys), pin_rows, pin_column, ROW_NUM, COLUMN_NUM );

const int max_buttons = ROW_NUM * COLUMN_NUM;
byte buttonPressed[max_buttons];

const byte debounce_interval_ms = 5;

void checkKeys()
{
  // Determine changes to button states
  keypad.getKeys();
  for (int i=0; i<LIST_MAX; i++)   // Scan the list of active keys
  {
    char key = keypad.key[i].kchar;
    if ( keypad.key[i].stateChanged )
    {
      keypad.key[i].stateChanged = false;
      switch (keypad.key[i].kstate)
      {
          case PRESSED:
            buttonPressed[keypad.key[i].kcode] = 1;
            if (gDebugToSerial)
            {
              Serial.print("down: ");
              Serial.println(key);
            }
            break;
          case HOLD:
            break;
          case RELEASED:
            buttonPressed[keypad.key[i].kcode] = 0;
            if (gDebugToSerial)
            {
              Serial.print("up:   ");
              Serial.println(key);
            }
            break;
          case IDLE:
            break;
      }
    }
  }

  // Determine the outcome of pressed buttons to joystick controls
  int hatDir = -1;
  for (int r = 0; r < ROW_NUM; r++)
  {
    for (int c = 0; c < COLUMN_NUM; c++)
    {
      char buttonId = keys[r][c];
      byte value = buttonPressed[r*COLUMN_NUM + c];
      
      // POV Hat position
      if (value)
      {
        switch (buttonId)
        {
        case pinHatA:
          hatDir = 45;
          break;
        case pinHatB:
          hatDir = 0;
          break;
        case pinHatC:
          hatDir = 315;
          break;
        case pinHatD:
          hatDir = 270;
          break;
        case pinHatE:
          hatDir = 225;
          break;
        case pinHatF:
          hatDir = 180;
          break;
        case pinHatG:
          hatDir = 135;
          break;
        case pinHatH:
          hatDir = 90;
          break;
        default:
          break;
        }
      }

      // Buttons
      switch (buttonId)
      {
        case pinUp:
          Joystick.button(1, value);
          break;
        case pinDown:
          Joystick.button(2, value);
          break;
        case pinForward:
          Joystick.button(3, value);
          break;
        case pinBack:
          Joystick.button(4, value);
          break;
        case pinExtraBack:
          Joystick.button(5, value);
          break;
        case pinExtraForward:
          Joystick.button(6, value);
          break;
        case pinTrigger:
          Joystick.button(10, value);
          break;
        case pinModeSwitch:
          Joystick.button(11, value);
          break;
        case pinHatButton:
          Joystick.button(20, value);
          break;
        default:
          break;
      }
    }
    Joystick.hat(hatDir);
  }
}

void
checkAxis()
{
  // read 4 analog inputs and use them for the joystick axis
  //if (mode != MODE_LOCKED)
  {
    axisThrottle.calcValue(analogRead(analogPinThrottle));
    axisHor.calcValue(analogRead(analogPinHor));
    axisVer.calcValue(analogRead(analogPinVer));
    
    Joystick.X(axisHor.value);
    Joystick.Y(axisVer.value);
    Joystick.Z(axisThrottle.value);
    //Joystick.Zrotate(analogRead(analogPinSlider));
  }  
}

void setup()
{
  Serial.begin(9600);
  Joystick.useManualSend(true);
  Joystick.hat(-1);
 
  FastLED.addLeds<WS2812, pinLed, GRB>(leds, NUM_LEDS);

  // Precalibration of axis
  
  axisThrottle.centerValue = 526;
  axisThrottle.maxValue = 1021;
  axisThrottle.minValue = 3;
  axisThrottle.deadZone = 20;
  
  axisHor.centerValue = 504;
  axisHor.maxValue = 1023;
  axisHor.minValue = 2;
  axisHor.deadZone = 25;
  
  axisVer.centerValue = 513;
  axisVer.maxValue = 1023;
  axisVer.minValue = 2;
  axisVer.deadZone = 25;
}

void setLeds()
{
  // Center detection for led color changes
  if (axisThrottle.value > 506 and axisThrottle.value < 516)
    throttleCentered = 1;
  else if (axisThrottle.value > 471 and axisThrottle.value < 551)
    throttleCentered = 2;
  else
    throttleCentered = 0;
  
  if (mode != previousMode || throttleCentered != previousThrottleCentered)
  {
    if (mode == MODE_LOCKED)
      leds[0] = CRGB (255, 0, 0); // red
    else if (mode == MODE_ALT)
      leds[0] = CRGB (0, 0, 255); // blue
    else
    {
      if (throttleCentered == 1)
        leds[0] = CRGB (0, 255, 0); // green
      else if (throttleCentered == 2)
        leds[0] = CRGB (255, 255, 0); // yellow
      else
        leds[0] = CRGB (255, 102, 0); // orange
    }
    
    previousMode = mode;
    previousThrottleCentered = throttleCentered;
    FastLED.show();
  }
}

void loop()
{
  checkAxis();
  checkKeys();

  Joystick.send_now();
/*
  if (buttonPressed[pinModeSwitch])
  {
    if (Serial)
      mode = MODE_ALT;
    else
      mode = MODE_LOCKED;
  }
  else
  {
    mode = MODE_NORMAL;
    if (axisThrottle > 506 and axisThrottle < 516)
      throttleCentered = 1;
    else if (axisThrottle > 471 and axisThrottle < 551)
      throttleCentered = 2;
    else
      throttleCentered = 0;
  }
  */
  //setLeds();

  delay(1);
}

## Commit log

2021-04-06 Added printed parts preview. Minor updates and clarifications
    [common.scad, knobs.scad, printed-parts.scad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]
2021-05-10 Printable case, lower profile and improved base and case. 3d code reorg and improved parametrization
    [commercial-parts.scad, common.scad, knobs.scad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]
2021-05-10 Printed parts stl updated
2021-05-10 Added hat switch knob into preview pic
    [throttle-handle.scad]
2021-05-27 Started proto 3 handle improvements: two more buttons, firmer assembly, better button module and hat assembly
    [commercial-parts.scad, common.scad, printed-parts.scad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]
2022-02-05 Prototype v3 (#3)
    * Use keyboard matrix, put hat switch to same board as other thumb plate switches, fixes to instructions, add circuit board design and part list
    * Updated thumb side circuit board design
    * Updated handle pics of v3 implementation
    [commercial-parts.scad, throttle-handle.scad, throttle-parameters.scad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]
